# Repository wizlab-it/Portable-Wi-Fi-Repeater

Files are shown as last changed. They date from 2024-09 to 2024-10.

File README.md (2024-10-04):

# Portable Wi-Fi Repeater

This is a battery-powered Portable Wi-Fi Repeater based on the ESP8266 board, than can be used to extend the range of a Wi-Fi Network in areas where it could be difficult to use standard Wi-Fi repeaters.

The repeater connects to the Wi-Fi Network to be extended and creates its own Wi-Fi Network. Traffic on the new Wi-Fi Network is routed through the original network.

A solar panel could be used to increase the battery life (18650 Li-ion 3.7V battery). When the battery level is low, the built-in led blinks 3 times every 15 seconds.

## Configuration Mode

When the device starts for the first time, it runs in *Configuration Mode*. An open Wi-Fi Network with SSID *PortWiFiRepeater-nnnn* (where *nnnn* is a 4-digits random number) is created.
Connecting to this network the configuration panel is shown automatically, to configure the Wi-Fi Network to extend and, optionally, the parameters of the network to create.
In the case the configuration panel is not shown automatically, open any browser and go to *http://192.168.1.1*
On the OLED display (if available) some info about the device status are shown.

The configuration panel shows the list of available Wi-Fi Networks, with details about their signal quality. The network to be extended can be selected from the list, and the PSK entered.
By default, the device creates a new Wi-Fi Network with the same SSID with the suffix "_ext", and same PSK.
Both the SSID and PSK of the new network can be customized clicking on the checkbox.
Clicking on the *Refresh* button, a new scan of the available Wi-Fi Networks is performed and the dropdown list is updated accordingly.
Clicking on the *Identify device* button, the built-in led blinks 20 times, to identify the device being configured.

When the configuration is complete, clicking on the *Save* button the parameters are saved in the local EEPROM. The led will blink fast 10 times to inform the configuration has been saved.
Rebooting the device, it will run in *Repeater Mode*.

### Configuration reset

To reset the configuration, press the button and keep it pressed when booting the device.
When the configuration has been reset the led will blink fast 10 times. If available, the OLED will show a message to inform the configuration has been removed.
After a configuration reset, the device can be configured again.

## Repeater Mode

When the device finds a valid configuration in the EEPROM during boot, it starts in *Repeater Mode*.
It first tries to connect to the original Wi-Fi Network, then it creates the new network.
Once the startup process is completed, Wi-Fi devices can connect to the new Wi-Fi Network, and their traffic will be routed automatically through the original network.
The OLED display will show some info about the original network signal quality, the number of connected stations, the battery status and the SSID of the original and new networks.
If the OLED display is not available, the signal quality of the original Wi-Fi Network can be checked pressing the button: the led will blink fast twice (to tell the signal quality will be shown), then after 1 second it will blink slow a number of times equal to the quality of the signal (0 to 5). For example, if the signal quality is 3, the led will blink twice fast, then after 1 second three times slow.

In the case the connection to the original network is lost, the device tried automatically to reconnect. On the OLED display, the *Reconnecting* message is shown.

## Credits and references

Created by [WizLab.it](https://www.wizlab.it/)

GitHub: [https://github.com/wizlab-it/temperature-monitor/](https://github.com/wizlab-it/temperature-monitor/)

[ESP8266 Documentation](https://arduino-esp8266.readthedocs.io/)

## License

This program is free software: you can redistribute it and/or modify it under the terms of the GNU General Public License as published by the Free Software Foundation, either version 3 of the License, or (at your option) any later version.

This program is distributed in the hope that it will be useful, but WITHOUT ANY WARRANTY; without even the implied warranty of MERCHANTABILITY or FITNESS FOR A PARTICULAR PURPOSE. See the GNU General Public License for more details.

To get a copy of the GNU General Public License, see [http://www.gnu.org/licenses/](http://www.gnu.org/licenses/)

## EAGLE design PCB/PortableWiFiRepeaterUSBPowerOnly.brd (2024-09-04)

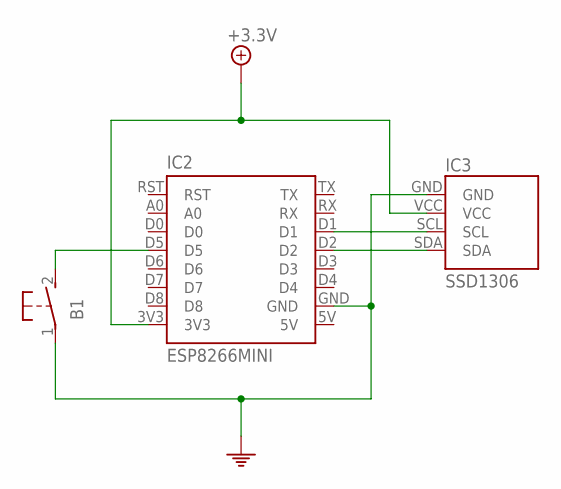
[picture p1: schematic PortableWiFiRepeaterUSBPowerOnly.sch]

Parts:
B1: BUTTONSIL2; SIL2
IC2: ESP8266MINI
IC3: SSD1306

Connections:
5V: IC2.5V
+3.3V: IC2.3V3, IC3.VCC
GND: B1.1, IC2.GND, IC3.GND
unnamed: B1.2 (S), IC2.D5
unnamed: IC2.D1, IC3.SCL
unnamed: IC2.D2, IC3.SDA

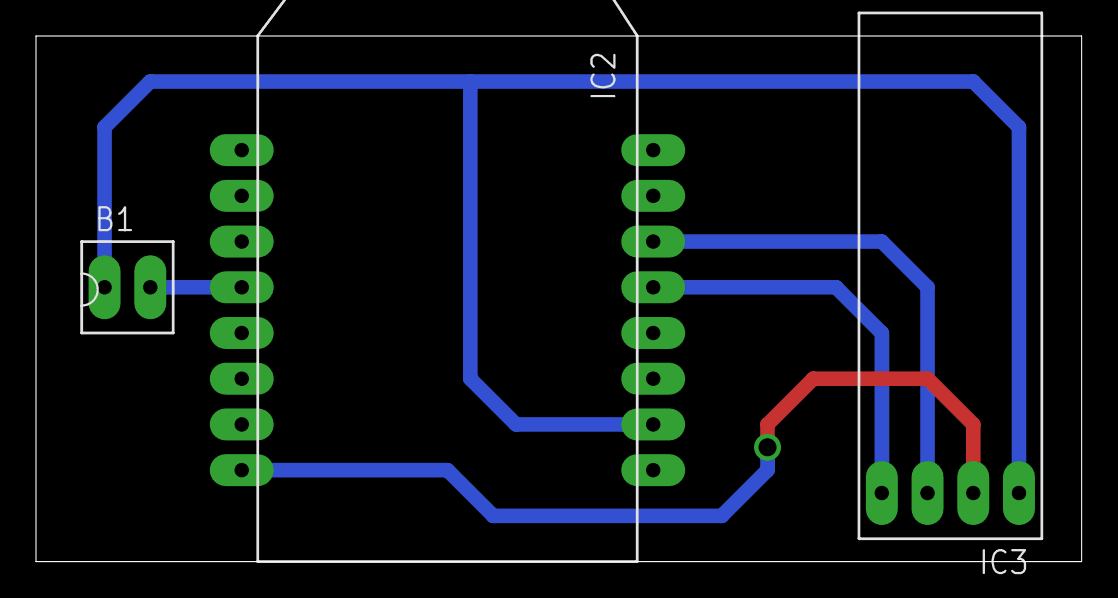
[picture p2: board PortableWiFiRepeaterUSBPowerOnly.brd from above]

Board: 2 copper layers, 58.1 x 29.2 mm, 3 parts (0 on the bottom side), 5 nets.

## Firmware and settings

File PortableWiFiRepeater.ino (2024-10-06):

/**
 * @package Portable WiFi Repeater
 * @author WizLab.it
 * @board Generic ESP8266
 * @version 20241006.077
 */

#include <Arduino.h>
#include <ESP8266WiFi.h>
#include <ESP8266WebServer.h>
#include <DNSServer.h>
#include <EEPROM.h>
#include <CRC32.h>
#include <Wire.h>
#include <Adafruit_GFX.h>
#include <Adafruit_SSD1306.h>
#include <lwip/napt.h>
#include <lwip/dns.h>
#include "ConfigWebServerPages.h"


/**
 * System Parameters
 */

//Low-battery
#define LOWBATTERY_PIN            A0
#define LOWBATTERY_COMPENSATION   2.10

//LED
// - [runtime] 3 mid-speed blinks every 15 seconds: battery low
// - [boot] 10 fast blinks: configuration deleted
// - [config] 10 fast blinks: configuration saved
// - [config] 20 fast blinks: identify device
// - [repeater + BTN1 pressed] 3 fast + 0.5 seconds delay + N slow blinks: STA signal quality (N = signal quality, 0 to 5)
#define LED_PIN 2 //GPIO2, D4
#define LED_ON LOW //Led is on when the pin is low
#define LED_OFF HIGH //Led is off when the pin is high

//OLED
#define OLED_ADDRESS 0x3C //OLED I2C Address
#define OLED_WIDTH 128 //OLED display width, in pixels
#define OLED_HEIGHT 32 //OLED display height, in pixels

//Buttons
#define BTN1_PIN 14 //GPIO14, D5

//Repeater
#define REPEATER_MODE_INIT 0
#define REPEATER_MODE_CONFIG 1
#define REPEATER_MODE_REPEATER 2
#define REPEATER_NAPT 1000
#define REPEATER_NAPT_PORT 10
#define REPEATER_CONFIG_SSID "PortWiFiRepeater-"

//Other generic constants
#define EEPROM_CONFIG_ADDRESS 0
#define SSID_LENGTH 40
#define PSK_LENGTH 30


/**
 * Structs
 */

//Repeater configuration
typedef struct {
  char staSSID[SSID_LENGTH + 1];
  char staPSK[PSK_LENGTH + 1];
  char apSSID[SSID_LENGTH + 4 + 1];
  char apPSK[PSK_LENGTH + 1];
} __RepeaterConfiguration;

//Repeater configuration package
typedef struct {
  __RepeaterConfiguration config;
  uint32_t crc;
} __RepeaterConfigurationPackage;

//Timers
struct {
  unsigned long batteryCheck = 0;
  unsigned long connectedStationsCheck = 0;
  unsigned long staStatus = 0;
  unsigned long reconnectTimeout = 0;
} __Timers;


/**
 * Global Variables
 */

__RepeaterConfigurationPackage REPEATER_CONFIG;
uint8_t REPEATER_MODE = REPEATER_MODE_INIT;
Adafruit_SSD1306 display(OLED_WIDTH, OLED_HEIGHT, &Wire, -1);
WiFiEventHandler apStationConnectedHandler;
WiFiEventHandler apStationDisconnectedHandler;
ESP8266WebServer configWebServer(80);
DNSServer configDnsServer;


//===================================================================================


/**
 * Setup
 */
void setup() {
  //Serial monitor
  Serial.begin(115200);
  Serial.println(F("\n\n\n\n\n"));
  Serial.println(F("************************************************************************"));
  Serial.println(F("***           ~  Portable Wi-Fi Repeater - by WizLab.it  ~           ***"));
  Serial.println(F("************************************************************************"));
  Serial.println(F("[~~~~~] Setup:"));

  //GPIO pins configuration
  pinMode(LOWBATTERY_PIN, INPUT);
  pinMode(BTN1_PIN, INPUT_PULLUP);

  //Led
  pinMode(LED_PIN, OUTPUT);
  digitalWrite(LED_PIN, LED_OFF);

  //OLED
  if(display.begin(SSD1306_SWITCHCAPVCC, OLED_ADDRESS)) {
    Serial.println(F(" [+] OLED activated"));
  } else {
    Serial.println(F(" [-] OLED init failed"));
  }

  //Splash screen
  display.clearDisplay();
  delay(250);
  display.cp437(true); // Use full 256 char 'Code Page 437'
  display.clearDisplay();
  display.setTextSize(1);
  display.setTextColor(WHITE);
  display.setCursor(43, 0);
  display.print("Portable");
  display.setCursor(24, 10);
  display.print("Wi-Fi Repeater");
  display.setCursor(30, 24);
  display.print("by WizLab.it");
  display.display();
  delay(2000);

  //After splash screen: clear display and check battery status
  display.clearDisplay();
  checkBattery();
  display.display();

  //Try to load a repeater configuration from EEPROM
  Serial.print(F(" [+] Read repeater configuration from EEPROM: "));
  bool hasValidConfig = repeaterConfigLoad();
  if(hasValidConfig) {
    REPEATER_MODE = REPEATER_MODE_REPEATER;
    Serial.println(F("OK"));
  } else {
    REPEATER_MODE = REPEATER_MODE_CONFIG;
    Serial.println(F("no valid configuration found."));
  }

  //Run the repeater mode
  if(REPEATER_MODE == REPEATER_MODE_CONFIG) {
    repeaterModeConfigRun();
  } else if(REPEATER_MODE == REPEATER_MODE_REPEATER) {
    repeaterModeRepeaterRun();
  }

  //Setup completed
  Serial.println(F("[~~~~~] Setup complete."));
  Serial.println(F("[~~~~~] Running:"));
}


/**
 * Loop
 */
void loop() {
  //Check battery
  checkBattery();

  //Check connected stations
  checkConnectedStations();

  //Loop actions when in Config mode
  if(REPEATER_MODE == REPEATER_MODE_CONFIG) {
    configDnsServer.processNextRequest();
    configWebServer.handleClient();
  }

  //Loop actions when in Repeater mode
  if(REPEATER_MODE == REPEATER_MODE_REPEATER) {
    //Check STA status
    checkStatusSTA();
  }
}


//===================================================================================


/**
 * Load repeater configuration from EEPROM
 */
bool repeaterConfigLoad() {
  //Init EEPROM
  EEPROM.begin(sizeof(__RepeaterConfigurationPackage));

  //Check if to reset configuration
  if(digitalRead(BTN1_PIN) == LOW) {
    repeaterConfigClear(true);
    Serial.print(F("\n [+] Configuration reset"));
    oledPrintLine(1, F("  * Configuration *"));
    oledPrintLine(2, F("  *     reset     *"));
    blinkLed(10, 1);
    delay(3000);
    ESP.restart();
  } else {
    //Read configuration and calculate CRC
    EEPROM.get(EEPROM_CONFIG_ADDRESS, REPEATER_CONFIG);
    uint32_t configCrc = CRC32::calculate((const uint8_t *)&REPEATER_CONFIG.config, sizeof(__RepeaterConfiguration));

    //Check if configuration is valid
    if(REPEATER_CONFIG.crc == configCrc) {
      return true;
    }

    //If config is not valid, then clear it
    repeaterConfigClear(false);
  }

  return false;
}

bool repeaterConfigSave() {
  //Validate new configuration CRC
  uint32_t configCrc = CRC32::calculate((const uint8_t *)&REPEATER_CONFIG.config, sizeof(__RepeaterConfiguration));
  if(REPEATER_CONFIG.crc == configCrc) {
    EEPROM.put(EEPROM_CONFIG_ADDRESS, REPEATER_CONFIG);
    EEPROM.commit();
    return true;
  }
  return false;
}

/**
 * Clear repeater configuration
 */
void repeaterConfigClear(bool resetEeprom) {
  memset((void *)&REPEATER_CONFIG, 0x00, sizeof(__RepeaterConfigurationPackage));

  if(resetEeprom) {
    EEPROM.put(EEPROM_CONFIG_ADDRESS, REPEATER_CONFIG);
    EEPROM.commit();
  }
}

/**
 * Repeater mode
 */
void repeaterModeRepeaterRun() {
  Serial.println(F(" [+] Activating repeater mode..."));

  //Connect to Access Point that has to be repeated
  uint16_t connectingTimer = 0;
  WiFi.mode(WIFI_STA);
  WiFi.begin(REPEATER_CONFIG.config.staSSID, REPEATER_CONFIG.config.staPSK);
  Serial.print(F("    [+] connecting to network to be repeated: "));
  oledPrintLine(2, "    Connecting...");
  while(WiFi.status() != WL_CONNECTED) {
    Serial.print(F("."));
    delay(500);

    //If trying to connect for more than 3 minutes, then restart the ESP
    connectingTimer++;
    if(connectingTimer > (3 * 60 * 2)) {
      Serial.println("Restart.");
      oledPrintLine(2, "    Restart");
      delay(2500);
      ESP.restart();
    }
  }
  Serial.printf(" OK! (IP: %s)\n", WiFi.localIP().toString().c_str());
  oledPrintLine(2, "     Connected!");

  //Configure repeater network
  Serial.print(F("    [+] configuring repeater network: "));
  IPAddress localIp = IPAddress(10, random(0, 255), random(0, 255), 1);
  WiFi.softAPConfig(localIp, localIp, IPAddress(255, 255, 255, 0));
  auto &dhcpserver = WiFi.softAPDhcpServer();
  dhcpserver.setDns(WiFi.dnsIP(0));
  Serial.printf("OK! (IP: %s)\n", WiFi.softAPIP().toString().c_str());

  //Activate repeater network
  Serial.print(F("    [+] activate repeater network: "));
  WiFi.softAP(REPEATER_CONFIG.config.apSSID, REPEATER_CONFIG.config.apPSK);
  Serial.printf("OK! (SSID: %s)\n", WiFi.softAPSSID().c_str());

  //Activate NAPT
  Serial.print(F("    [+] activate NAPT: "));
  err_t naptStatus = ip_napt_init(REPEATER_NAPT, REPEATER_NAPT_PORT);
  if(naptStatus == ERR_OK) {
    naptStatus = ip_napt_enable_no(SOFTAP_IF, 1);
  }
  if(naptStatus == ERR_OK) {
    Serial.println(F("OK!\n [+] Repeater mode activated successfully!"));
    Serial.printf("    [i] repeated network: %s\n", REPEATER_CONFIG.config.staSSID);
    Serial.printf("    [i] repeater network: %s\n", REPEATER_CONFIG.config.apSSID);
    oledPrintLine(1, REPEATER_CONFIG.config.staSSID);
    oledPrintLine(2, "        <===>");
    oledPrintLine(3, REPEATER_CONFIG.config.apSSID);

    //Connection handlers
    apStationConnectedHandler = WiFi.onSoftAPModeStationConnected(&apOnStationConnected);
    apStationDisconnectedHandler = WiFi.onSoftAPModeStationDisconnected(&apOnStationDisconnected);
  } else {
    Serial.println(F(" Failed."));
  }
}

/**
 * Config mode
 */
void repeaterModeConfigRun() {
  Serial.println(F(" [+] Activating configuration mode..."));

  //Activate access point
  Serial.print(F("    [+] activate config WiFi network: "));
  String configModeSSID = REPEATER_CONFIG_SSID + String(random(1000, 9999));
  IPAddress localIp = IPAddress(192, 168, 1, 1);
  WiFi.softAPConfig(localIp, localIp, IPAddress(255, 255, 255, 0));
  auto &dhcpserver = WiFi.softAPDhcpServer();
  dhcpserver.setDns(localIp);
  WiFi.softAP(configModeSSID);
  Serial.printf("OK! (SSID: %s)\n", WiFi.softAPSSID().c_str());

  //Connection handlers
  apStationConnectedHandler = WiFi.onSoftAPModeStationConnected(&apOnStationConnected);
  apStationDisconnectedHandler = WiFi.onSoftAPModeStationDisconnected(&apOnStationDisconnected);

  //Activate configuration web server
  Serial.print(F("    [+] activate config web server: "));
  configWebServerEngine();
  configWebServer.begin();
  char configURL[30];
  sprintf(configURL, "http://%s/", WiFi.softAPIP().toString().c_str());
  Serial.printf("OK! (URL: %s)\n", configURL);

  //Activate DNS for local resolution to configuration portal
  Serial.print(F("    [+] activate config DNS server: "));
  configDnsServer.start(53, "*", WiFi.softAPIP());
  Serial.println(F("OK!"));

  //Print configuration portal info on OLED
  oledPrintLine(1, F(" *** CONFIG MODE ***"));
  oledPrintLine(2, configModeSSID);
  oledPrintLine(3, String(configURL));
}

/**
 * Web Server Engine (configure pages)
 */
void configWebServerEngine() {
  //Configuration portal
  configWebServer.on("/", configWebServerRoot);

  //Captive portal URLs
  configWebServer.on("/portal", configWebServerRoot);
  configWebServer.on("/portal/index.php", configWebServerRoot);
  configWebServer.on("/connecttest.txt", configWebServerRoot);
  configWebServer.on("/ncsi.txt", configWebServerRoot);
  configWebServer.on("/generate_204", configWebServerRoot);

  //Identify device
  configWebServer.on("/identify", []() {
    Serial.println(F("Config Web Server: device identified"));
    blinkLed(20, 1);
    configWebServer.send(200, "text/html", F("OK"));
  });

  //Reboot device
  configWebServer.on("/reboot", []() {
    ESP.restart();
  });

  //Page not found
  configWebServer.onNotFound([]() {
    configWebServer.send(404, "text/plain", "Page Not Found (" + configWebServer.uri() + ")");
  });
}

/**
 * Web Server Page: configuration portal
 */
void configWebServerRoot() {

  //If POST, then check info and save configuration
  if(configWebServer.method() == HTTP_POST) {

    //Save Repeated Network
    configWebServer.arg("staSSID").toCharArray(REPEATER_CONFIG.config.staSSID, SSID_LENGTH);
    configWebServer.arg("staPSK").toCharArray(REPEATER_CONFIG.config.staPSK, PSK_LENGTH);

    //Save Repeater Network
    configWebServer.arg("apSSID").toCharArray(REPEATER_CONFIG.config.apSSID, SSID_LENGTH);
    configWebServer.arg("apPSK").toCharArray(REPEATER_CONFIG.config.apPSK, PSK_LENGTH);

    //If Repeater SSID is empty, then create one based on the Repeated Network
    if(strncmp(REPEATER_CONFIG.config.apSSID, "", SSID_LENGTH) == 0) {
      sprintf(REPEATER_CONFIG.config.apSSID, "%s_ext", REPEATER_CONFIG.config.staSSID, SSID_LENGTH);
    }

    //If Repeater PSK is empty, then use the same PSK of the Repeated Network
    if(strncmp(REPEATER_CONFIG.config.apPSK, "", PSK_LENGTH) == 0) {
      strncpy(REPEATER_CONFIG.config.apPSK, REPEATER_CONFIG.config.staPSK, PSK_LENGTH);
    }

    //Calculate configuration CRC
    REPEATER_CONFIG.crc = CRC32::calculate((const uint8_t *)&REPEATER_CONFIG.config, sizeof(REPEATER_CONFIG.config));

    //Save new configuration on EEPROM
    if(repeaterConfigSave()) {
      Serial.println(F(" [+] New configuration saved on EEPROM"));
      oledPrintLine(3, F("   * CONFIG OK! *"));
      blinkLed(10, 1);
    } else {
      Serial.println(F(" [-] New configuration not saved on EEPROM: invalid configuration"));
      oledPrintLine(3, F("   * CONFIG KO. *"));
    }

    //Output HTML
    String html = String(configurationPortalHtmlLayout);
    html.replace("%BODY_CONTENT%", configurationPortalHtmlConfigSaved);
    configWebServer.send(200, "text/html", html);

  } else {

    //Build available Wi-Fi Networks list
    String availableNetworks = "";
    int numberOfNetworks = WiFi.scanNetworks();
    for(int i=0; i<numberOfNetworks; i++) {
      availableNetworks += "<option value=\"" + WiFi.SSID(i) + "\">" + WiFi.SSID(i) + " (Quality: " + String(getSignalLevelFromRSSI(WiFi.RSSI(i))) + ")</option>";
    }

    //Output HTML
    String html = String(configurationPortalHtmlLayout);
    html.replace("%BODY_CONTENT%", configurationPortalHtmlConfigForm);
    html.replace("%AVAILABLE_NETWORKS%", availableNetworks);
    configWebServer.send(200, "text/html", html);

  }
}

/**
 * Check battery status
 */
void checkBattery() {
  //Timer check
  if(__Timers.batteryCheck > millis()) return;
  __Timers.batteryCheck = millis() + 60000;

  //Read battery voltage
  long batteryVoltageRaw = analogRead(LOWBATTERY_PIN);
  float batteryVoltageVolt = (map(batteryVoltageRaw, 10, 1014, 0, 3000) / 1000.0) * LOWBATTERY_COMPENSATION; //Map is 10-1014 due to A/D error. Value is doubled because of the voltage divider, plus compensation due to voltage divider

  //If battery voltage is lower than 3.35V, it means its powered via USB power supply
  if(batteryVoltageVolt < 3.35) {
    Serial.printf(" [i] USB power supply\n");

    //Draw plug icon
    display.fillRect((OLED_WIDTH - 20), 0, 20, 8, BLACK);
    display.drawLine((OLED_WIDTH - 20), 4, (OLED_WIDTH - 16), 4, WHITE);
    display.fillCircle((OLED_WIDTH - 13), 4, 3, WHITE);
    display.fillRect((OLED_WIDTH - 11), 1, 4, 7, WHITE);
    display.drawLine((OLED_WIDTH - 7), 2, (OLED_WIDTH - 5), 2, WHITE);
    display.drawLine((OLED_WIDTH - 7), 6, (OLED_WIDTH - 5), 6, WHITE);
  } else {
    //Battery level on serial monitor
    Serial.printf(" [i] Battery voltage: %0.2f V (Raw: %d)\n", batteryVoltageVolt, batteryVoltageRaw);

    //Battery level on OLED
    display.fillRect((OLED_WIDTH - 20), 0, 20, 8, BLACK);
    display.drawRoundRect((OLED_WIDTH - 20), 0, 18, 7, 2, WHITE);
    display.fillRoundRect((OLED_WIDTH - 3), 2, 3, 3, 2, WHITE);
    if(batteryVoltageVolt > 3.60) display.fillRect((OLED_WIDTH - 18), 2, 4, 3, WHITE);
    if(batteryVoltageVolt > 3.75) display.fillRect((OLED_WIDTH - 13), 2, 4, 3, WHITE);
    if(batteryVoltageVolt > 3.90) display.fillRect((OLED_WIDTH - 8), 2, 4, 3, WHITE);
    display.display();

    //Battery level on led (3 mid-speed blinks if low-battery)
    if(batteryVoltageVolt < 3.60) blinkLed(3, 2);
  }
}

/**
 * Check connected stations
 */
void checkConnectedStations() {
  //Timer check
  if(__Timers.connectedStationsCheck > millis()) return;
  __Timers.connectedStationsCheck = millis() + 5000;

  //Print connected stations
  Serial.printf(" [i] Connected stations: %d\n", WiFi.softAPgetStationNum());
  display.fillRect((OLED_WIDTH - 60), 0, 36, 8, BLACK);
  display.setTextSize(1);
  display.setCursor((OLED_WIDTH - 60), 0);
  display.printf("STA:%d", WiFi.softAPgetStationNum());
  display.display();
}

/**
 * Check STA status
 */
void checkStatusSTA() {
  //Timer check
  if(__Timers.staStatus > millis()) return;
  __Timers.staStatus = millis() + 1000;

  //Get signal level based on RSSI
  int8_t signalLevel = getSignalLevelFromRSSI(WiFi.RSSI());

  //Print STA connection status
  if(WiFi.status() == WL_CONNECTED) {
    oledPrintLine(2, "        <===>");
    __Timers.reconnectTimeout = 0;

    //If BTN1 is pressed, then show RSSI with led blinks
    if(digitalRead(BTN1_PIN) == LOW) {
      blinkLed(2, 1); //Two fast blinks: identify RSSI-on-led
      delay(500);
      blinkLed(signalLevel, 3); //Slow blinks (0 to 5) based on signal level
      delay(3000);
    }
  } else {
    oledPrintLine(2, "   Reconnecting...");
    if(__Timers.reconnectTimeout == 0) {
      __Timers.reconnectTimeout = millis() + (3 * 60 * 1000);
    } else {
      //If trying to reconnect for more than 3 minutes, then restart the ESP
      if(__Timers.reconnectTimeout < millis()) {
        Serial.println("Restart.");
        oledPrintLine(2, "    Restart");
        delay(2500);
        ESP.restart();
      }
    }
  }

  //Print STA RSSI
  display.fillRect(0, 0, 47, 8, BLACK);
  display.setTextSize(1);
  display.setCursor(0, 0);
  display.printf("WiFi");
  for(int8_t i=1; i!=6; i++) {
    if(signalLevel < i) {
      display.fillRect((22 + (4 * i)), 5, 3, 1, WHITE);
    } else {
      display.fillRect((22 + (4 * i)), 1, 3, 5, WHITE);
    }
  }

  display.display();
}

/**
 * Blink led
 * @param speed: 1:fast; 2:medium; 3:slow
 */
void blinkLed(uint8_t numberOfBlinks, uint8_t speed) {
  if(speed < 1) speed = 1;
  if(speed > 3) speed = 3;
  speed = speed * 2 - 1;
  for(uint8_t i=numberOfBlinks; i!=0; i--) {
    digitalWrite(LED_PIN, LED_ON);
    delay(10 * speed);
    digitalWrite(LED_PIN, LED_OFF);
    delay(100 * speed);
  }
}

/**
 * Print message on OLED
 */
void oledPrintLine(uint8_t line, String message) {
  if(line < 1) return;
  if(line > 3) return;
  display.fillRect(0, (line * 8), OLED_WIDTH, 8, BLACK);
  display.setTextSize(1);
  display.setCursor(0, (line * 8));
  display.print(message);
  display.display();
}

/**
 * Handlers when station connects/disconnects to/from the Access Point
 */
void apOnStationConnected(const WiFiEventSoftAPModeStationConnected& evt) {
  Serial.printf(" [i] WiFi Access Point: Station connected: %x:%x:%x:%x:%x:%x (count: %d)\n", evt.mac[0], evt.mac[1], evt.mac[2], evt.mac[3], evt.mac[4], evt.mac[5], WiFi.softAPgetStationNum());
}
void apOnStationDisconnected(const WiFiEventSoftAPModeStationDisconnected& evt) {
  Serial.printf(" [i] WiFi Access Point: Station disconnected: %x:%x:%x:%x:%x:%x (count: %d)\n", evt.mac[0], evt.mac[1], evt.mac[2], evt.mac[3], evt.mac[4], evt.mac[5], WiFi.softAPgetStationNum());
}

/**
 * Claculate Wi-Fi signal level from RSSI
 * @return signal level from 0 (worst) to 5 (best)
 */
int8_t getSignalLevelFromRSSI(long rssi) {
  if(rssi > 0) return 0; //If RRSI is >0, then it's not connected
  if(rssi > -63) return 5;
  if(rssi > -69) return 4;
  if(rssi > -73) return 3;
  if(rssi > -76) return 2;
  if(rssi > -80) return 1;
  return 0;
}

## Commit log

2024-09-04 External USB power supply icon
    [PortableWiFiRepeater.brd, PortableWiFiRepeater.sch, PortableWiFiRepeaterUSBPowerOnly.brd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]
2024-10-03 Added automatic ESP restart if connection to the WiFi network to be repeated takes too long
    [PortableWiFiRepeater.ino]
2024-10-06 Added automatic ESP restart if reconnection to the WiFi network to be repeated takes too long
    [PortableWiFiRepeater.ino]
